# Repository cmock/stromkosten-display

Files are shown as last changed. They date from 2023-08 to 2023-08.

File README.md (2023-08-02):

# Stromkosten-Display

Zeigt auf einer 8x8-Matrix aus WS2812-LEDs die Strompreise der
nächsten Stunden und den Status des Stromnetzes an. 

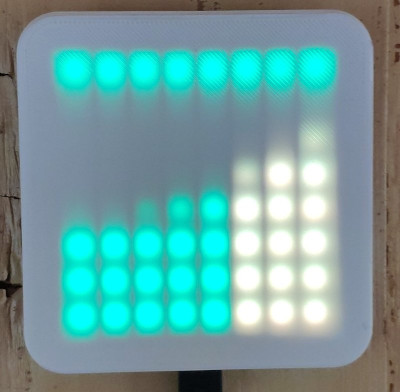
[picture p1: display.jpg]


Primär interessant für österreichische Haushalte mit dynamischen
Stromtarifen, die Idee ist, die Preise im Blick zu haben, bevor man
Großverbraucher einschaltet.

Die Preise kommen über die
[aWATTar-API](https://www.awattar.at/services/api/), der Status von
[APG](https://www.apg.at/powermonitor/#c3883). 

## Ablesen

Der linke senkrechte Balken ist der Preis der aktuellen vollen Stunde,
nach rechts sind dann die folgenden Stunden.

Die Länge und Farbe der Balken gibt den Preis an, grün bis 8¢/kWh,
gelb bis 12¢/kWh, rot darüber, und blau für negative Preise.

Der horizontale Balken ganz oben ist der Status des Stromnetzes gemäß
[APG Powermonitor](https://www.apg.at/powermonitor/), passend zu den
stundenweisen Preisbalken darunter. Grün ist OK, Rot ist Spitzenlast.

## Hardware

* Ein ESP32, das Gehäuse ist für
  [diesen](https://www.az-delivery.de/products/esp32-dev-kit-c-unverlotet?variant=32437204549728).
  Tunlichst einen ohne Pin-Header nehmen, im Gehäuse ist dafür kein Platz.
* eine 8x8-Matrix aus WS2812-RGB-LEDs, wie [diese](https://www.az-delivery.de/products/u-64-led-panel?variant=40362432466)
* Ein 3D-gedrucktes Gehäuse, siehe Directory [CAD](./CAD/)
  
### Aufbau

5V und GND der LED-Matrix verbinden, GPIO16 vom ESP (`LED_PIN` im Code) mit
dem Datenpin der Matrix, fertig.

Evtl zuerst mal [WLED](https://install.wled.me/) draufflashen, das
geht einfach und man kann die Funktion der Hardware damit schön und
bunt prüfen.

### Gehäuse

[basis.stl](CAD/basis.stl) in einer undurchsichtigen Farbe,
[abdeckung.stl](CAD/abdeckung.stl) in transparentem oder weißem
Filament drucken.

Die LED-Matrix von hinten in die Basis klemmen (oder mit Heißkleber
nachhelfen), Pixel #1 kommt nach links oben. Das ESP-board einfach
dahinterlegen, sinnvollerweise mit einer Isolationsschicht dazwischen.
Mit 3mm-Spaxen an die Wand, Abdeckung drauf, fertig.

## Installation

Software-Installation: basiert auf
[PlatformIO](https://platformio.org/).

1) `include/config.h.dist` auf `include/config.h` kopieren und
editieren (WiFi-Daten, Schwellwerte für die Display-Farben)

2) `platformio.ini` ggf anpassen in sachen Upload

3) `pio run -t upload`

## Security-Warnung

Die APIs sind über HTTPS erreichbar. TL;DR: *die
Zertifikatsverifikation ist im Code ausgeschaltet.*

Da die HTTPS-Libraries für ESP32 nur ein einziges Root-Cert
unterstützen, besteht bei korrekter Verwendung das Problem, daß man
bei Änderung einer der CAs der API-Server dies erst mitbekommt, wenn
es schon geschehen ist, dann das korrekte Cert finden und in den Code
integrieren muß (oder mit noch mehr Programmieraufwand das im
Filesystem speichern und einen Mechanismus zum Updaten ohne
Recompilieren vorsehen muß). 

Das war mir zu aufwendig und widerspricht der Idee "Display, das
einfach an der Wand hängt und funktioniert."

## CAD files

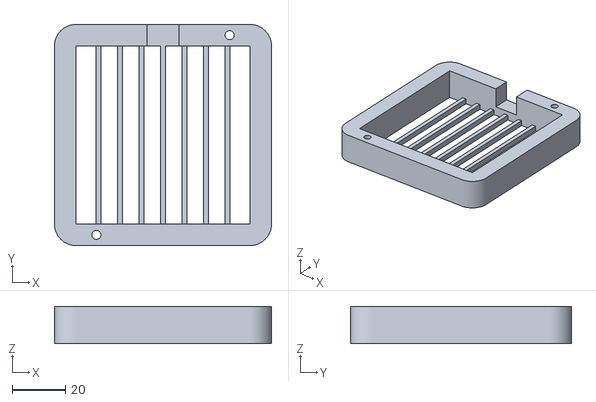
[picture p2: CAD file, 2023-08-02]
CAD/basis.stl
81.5 x 83.0 x 14.0

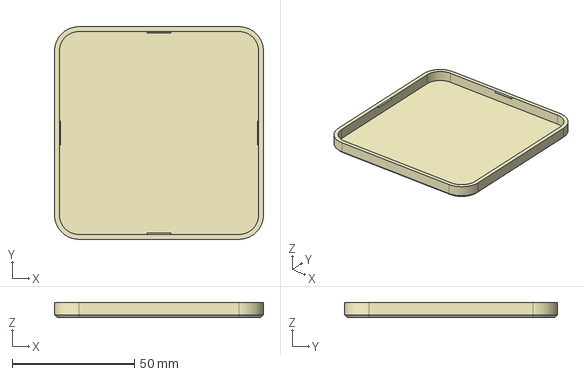
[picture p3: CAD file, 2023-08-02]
CAD/case.FCStd
85.5 x 87.0 x 6.00 mm

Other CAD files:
CAD/abdeckung.stl

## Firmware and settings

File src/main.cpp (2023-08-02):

#include <NeoPixelBusLg.h>
#include <ArduinoJson.h>
#include <FS.h>
#include <LittleFS.h>
#include <WiFi.h>
#include <WiFiMulti.h>
#include <HTTPClient.h>
#include <WiFiClientSecure.h>
#include <time.h>
#include <sntp.h>

#include "config.h"

#define LED_ROWS 8
#define LED_COLS 8
#define NUM_LEDS (LED_ROWS * LED_COLS)
#define LED_PIN 16

#define PRICE_PATH "/prices.json"
#define POWER_MONITOR_PATH "/power-monitor.json"
// how long before expiry will we try and fetch?
#define DATA_EXPIRY_BUFFER 3600
#define DATA_FETCH_RETRY 600
// how often to check if display update is necessary, in milliseconds
#define DISPLAY_INTERVAL (10*1000)

#define USER_AGENT "energy-cost-display/0.1 (ESP32HTTPClient) cm@tahina.priv.at"

#define AWATTAR_API_URL "https://api.awattar.at/v1/marketdata"

#define POWER_MONITOR_API_URL "https://awareness.cloud.apg.at/api/v1/PeakHourStatus"

#define FORMAT_LITTLEFS_IF_FAILED true


// global system state
struct {
  bool wifi_up, valid_time, valid_price_data, valid_monitor_data;
  time_t price_expiry, powermonitor_expiry,
    last_fetch_price, last_fetch_powermonitor;
} state = { false, false, false, false,
  0, 0, 0, 0,
};

NeoPixelBusLg<NeoGrbFeature, NeoEsp32I2s0Ws2812xMethod> leds(NUM_LEDS, LED_PIN);
NeoTopology<RowMajorLayout> topo(LED_ROWS, LED_COLS);

RgbColor red(255, 0, 0);
RgbColor green(0, 255, 0);
RgbColor yellow(255, 200, 0);
RgbColor blue(0,120,255);
RgbColor white(255);
RgbColor black(0);

const uint16_t left = 0;
const uint16_t right = LED_COLS - 1;
const uint16_t top = 0;
const uint16_t bottom = LED_ROWS - 1;

//const size_t json_capacity = JSON_OBJECT_SIZE(3) + 25 * JSON_OBJECT_SIZE(4);
const size_t json_capacity = 2048;
StaticJsonDocument<json_capacity> json_doc;
#define MAX_JSON_LEN 5120

#define BIG_BUF_LEN 4096
char big_buf[BIG_BUF_LEN], big_buf2[BIG_BUF_LEN];

double prices[LED_COLS];
uint16_t powermonitor[LED_COLS];

WiFiMulti wifiMulti;

bool GET(const char *url, char *buf, size_t maxlen) {
  WiFiClientSecure *client = new WiFiClientSecure;
  bool error = false;
  if(client) {
    // this client only accepts a single root cert, so either you go chasing
    // new root certs everytime the upstream server changes cert, or you
    // just skip certificate verification...
    client->setInsecure();
    HTTPClient https;
    https.setUserAgent(USER_AGENT);
    if(https.begin(*client, url)) {
      int httpCode = https.GET();
      Serial.printf("GET %s: code %d\n", url, httpCode);
      if(httpCode > 0) {
	if(httpCode == HTTP_CODE_OK || httpCode == HTTP_CODE_MOVED_PERMANENTLY) {
	  String payload = https.getString();
	  strncpy(buf, payload.c_str(), maxlen);
	}
      } else {
	Serial.println("GET failed");
	error = true;
      }
      https.end();
    } else {
      Serial.println("HTTPS.begin failed");
      error = true;
    }
    delete client;
  }
  return !error;
}

// returns timestamp of last entry, or 0 on error
time_t parse_awattar_json(char input[], time_t now) {
  time_t last_timestamp = 0;
  
  DeserializationError error = deserializeJson(json_doc, input, MAX_JSON_LEN);
  if(error) {
    Serial.print("Awattar: deserializeJson() failed: ");
    Serial.println(error.c_str());
    Serial.printf("Capacity: %d\n", json_doc.capacity());
    return 0;
  }

  const char *object = json_doc["object"];
  if(strcmp(object, "list")) {
    Serial.println("JSON: object != list");
    return 0;
  }

  now -= (now % 3600); // round to hour
  
  for (JsonObject data_item : json_doc["data"].as<JsonArray>()) {
    time_t start_timestamp = data_item["start_timestamp"].as<long long>()/1000;
    time_t end_timestamp = data_item["end_timestamp"].as<long long>()/1000;
    double marketprice = data_item["marketprice"]; 
    const char* unit = data_item["unit"];
    if(strcmp(unit, "Eur/MWh")) {
      Serial.println("JSON: unit not Eur/Mwh");
      return 0;
    }
    if(start_timestamp > last_timestamp)
      last_timestamp = start_timestamp;
    if(start_timestamp < now)
      continue;
    time_t slot = (start_timestamp - now)/3600;
    char buf[1024];
    sprintf(buf, "%d %d %.2f\n", start_timestamp, slot, marketprice);
    Serial.print(buf);
    if(slot >= LED_COLS)
      continue;
    prices[slot] = marketprice;
  }
  return last_timestamp;
}

// returns timestamp of "FirstUTC"
time_t parse_power_monitor_json(char input[], time_t now) {
  time_t first_timestamp = 0;
  
  DeserializationError error = deserializeJson(json_doc, input, MAX_JSON_LEN);
  if(error) {
    Serial.print("power_monitor: deserializeJson() failed: ");
    Serial.println(error.c_str());
    Serial.printf("Capacity: %d\n", json_doc.capacity());
    return 0;
  }

  const char *firstutc = json_doc["FirstUtc"];
  if(firstutc == NULL) {
    Serial.println("can't find FirstUtc");
    return 0;
  }
  Serial.printf("FirstUTC = <%s>\n", firstutc);
  struct tm tm;
  char *p = strptime(firstutc, "%Y-%m-%dT%H:%M:%SZ", &tm);
  if(p == NULL || *p != 0) {
    Serial.printf("strptime failed for 'FirstUtc' %s\n", firstutc);
    return 0;
  }
  first_timestamp = mktime(&tm); // should use timegm(), but that doesn't exist

  uint16_t dflt = json_doc["DefaultStatus"];
  Serial.printf("FirstUTC %d, DefaultStatus %d\n", first_timestamp, dflt);

  for(uint16_t i = 0; i < LED_COLS; i++)
    powermonitor[i] = dflt;

  now -= (now % 3600); // round to hour
  
  for (JsonObject info : json_doc["StatusInfos"].as<JsonArray>()) {
    const char *utc = info["utc"];
    uint16_t s = info["s"];
    char *p = strptime(utc, "%Y-%m-%dT%H:%M:%SZ", &tm);
    if(p == NULL || *p != 0) {
      Serial.printf("strptime failed for 'utc' %s\n", firstutc);
      return 0;
    }
    time_t utc_t = mktime(&tm);
    int16_t hrs = (utc_t - now)/3600;
    if(hrs >= 0 && hrs < LED_COLS)
      powermonitor[hrs] = s;
  }
  return first_timestamp;
}

void writeFile(fs::FS &fs, const char * path, const char * message){
    Serial.printf("Writing file: %s\r\n", path);

    File file = fs.open(path, FILE_WRITE);
    if(!file){
        Serial.println("- failed to open file for writing");
        return;
    }
    if(file.print(message)){
        Serial.println("- file written");
    } else {
        Serial.println("- write failed");
    }
    file.close();
}

void fetch_awattar() {
  time_t now = time(NULL);
  // fetch
  if(!GET(AWATTAR_API_URL, big_buf, BIG_BUF_LEN))
    return;
  // copy big_buf because json parsing modifies it...
  memcpy(big_buf2, big_buf, BIG_BUF_LEN);
  // check
  time_t last_price = parse_awattar_json(big_buf, now);
  if(last_price == 0)
    return;
  // update expiry time
  state.price_expiry = last_price - 9 * 3600;
  state.valid_price_data = true;
  // write cache
  writeFile(LittleFS, PRICE_PATH, big_buf2);
}

void fetch_power_monitor() {
  time_t now = time(NULL);
  // fetch
  if(!GET(POWER_MONITOR_API_URL, big_buf, BIG_BUF_LEN))
    return;
  // copy big_buf because json parsing modifies it...
  memcpy(big_buf2, big_buf, BIG_BUF_LEN);
  // check
  time_t start_time = parse_power_monitor_json(big_buf, now);
  if(start_time == 0)
    return;
  // update expiry time
  state.powermonitor_expiry = start_time + 25 * 3600;
  state.valid_monitor_data = true;
  // write cache
  writeFile(LittleFS, POWER_MONITOR_PATH, big_buf2);
}
  

bool readFile(fs::FS &fs, const char * path, char *buf, size_t maxlen){
  char *p = buf;
  size_t avail = maxlen;
  Serial.printf("Reading file: %s\r\n", path);

  File file = fs.open(path);
  if(!file || file.isDirectory()){
    Serial.println("- failed to open file for reading");
    return false;
  }

  Serial.println("- read from file:");
  while(file.available()){
    size_t n = file.readBytes(p, avail);
    Serial.println(n);
    p+=n;
    avail-=n;
    if(avail <= 0) {
      Serial.println("No more buffer space while reading");
      return false;
    }
  }
  file.close();
  return true;
}

// read cached data and expiry timestamps
bool read_caches() {
  time_t now = time(NULL);
  
  if(readFile(LittleFS, PRICE_PATH, big_buf, BIG_BUF_LEN)) {
    Serial.println("read " PRICE_PATH);
    time_t last_price = parse_awattar_json(big_buf, now);
    if(last_price != 0) {
      // update expiry time
      state.price_expiry = last_price - 9 * 3600;
      state.valid_price_data = true;
    }
  }
  if(readFile(LittleFS, POWER_MONITOR_PATH, big_buf, BIG_BUF_LEN)) {
    Serial.println("read " POWER_MONITOR_PATH);
    time_t first_monitor = parse_power_monitor_json(big_buf, now);
    if(first_monitor != 0) {
      state.powermonitor_expiry = first_monitor + 25 * 3600;
      state.valid_monitor_data = true;
    }
  }
  return true;
}


// col: 0..7, len: 0..8
void bar(uint16_t col, double len, RgbColor color, RgbColor bgcolor) {
  if(col >= LED_COLS)
    col = LED_COLS-1;
  if(len > 1.0)
    len = 1.0;

  uint16_t full = fabs(len) * (LED_ROWS-1); // integer part
  float frac = fabs(len) * (LED_ROWS-1) - full;
  //  Serial.printf("blend: len %.2f, full %d, frac %.1f\n", len, full, frac);
  
  // clear
  for(uint16_t y = 0; y < LED_ROWS; y++)
    leds.SetPixelColor(topo.Map(col, y), bgcolor);
  for(uint16_t y = 1; y <= full; y++)
    leds.SetPixelColor(topo.Map(col, LED_ROWS-y), color);
  if(frac > 0.09)
    leds.SetPixelColor(topo.Map(col, LED_ROWS-full-1),
		       RgbColor::LinearBlend(black, color, frac));
  // always set lowest pixel
  leds.SetPixelColor(topo.Map(col, LED_ROWS-1), color);
}

void printTime()
{
  struct tm timeinfo;
  time_t now;
  if(!getLocalTime(&timeinfo)){
    Serial.println("No time available (yet)");
    return;
  }
  Serial.println(&timeinfo, "%A, %B %d %Y %H:%M:%S");
  time(&now);
  Serial.println(now);
}

// Callback function (get's called when time adjusts via NTP)
void timeavailable(struct timeval *t)
{
  Serial.println("Got time adjustment from NTP!");
  state.valid_time = true;
}

void print_timers() {
  time_t now;
  time(&now);
  Serial.println("Timers:");
  Serial.print("Prices: ");
  Serial.print(state.price_expiry);
  Serial.print(" - ");
  Serial.println(state.last_fetch_price - now);
  Serial.print("Monitor: ");
  Serial.print(state.powermonitor_expiry);
  Serial.print(" - ");
  Serial.println(state.last_fetch_powermonitor - now);
}

void ls_littlefs() {
  File root = LittleFS.open("/");
  if(!root) {
    Serial.println("ls_littlefs: failed to open /");
    return;
  }
  if(!root.isDirectory()) {
    Serial.println("ls_littlefs: / is not a directory");
    return;
  }
  File file = root.openNextFile();
  while(file) {
    Serial.printf("%3s %6d %s\n", file.isDirectory() ? "DIR" : "",
		  file.size(), file.name());
    file = root.openNextFile();
  }
}
  

void setup() {
  Serial.begin(115200);
  while(!Serial);
  delay(2000);
  Serial.println();
  Serial.println("Starting...");
  Serial.print("json_capacity: "); Serial.println(json_capacity);
  //  FastLED.addLeds<NEOPIXEL, LED_PIN>(leds, NUM_LEDS);
  leds.Begin();
  leds.SetLuminance(LED_BRIGHTNESS);
  leds.ClearTo(black);
  leds.SetPixelColor(0, green); // show power on state
  leds.SetPixelColor(1, red); // show waiting for wifi
  leds.Show();

  sntp_set_time_sync_notification_cb( timeavailable );
  // we don't need local time offset
  configTime(0, 0, NTP_SERVER, NULL, NULL);
  
  WiFi.setHostname(HOSTNAME);
  wifiMulti.addAP(WIFI1_SSID, WIFI1_PSK);
  wifiMulti.addAP(WIFI2_SSID, WIFI2_PSK);


  if(!LittleFS.begin(FORMAT_LITTLEFS_IF_FAILED)){
    Serial.println("LittleFS Mount Failed");
    return;
  }
  
  Serial.println("LittleFS mounted, Running.");
  ls_littlefs();
}


void loop() {
  time_t now;
  static unsigned long last_display_millis = 0;

  if(wifiMulti.run() == WL_CONNECTED) {
    state.wifi_up = true;
  } else {
    state.wifi_up = false;
  }

  if(state.wifi_up && state.valid_time &&
     last_display_millis + DISPLAY_INTERVAL < millis()) {
    last_display_millis = millis();
    // check if we need to do some API calls
    read_caches();
    time(&now);
    if(state.last_fetch_price + DATA_FETCH_RETRY < now &&
       state.price_expiry < now + DATA_EXPIRY_BUFFER) {
      Serial.println("fetch awattar");
      fetch_awattar();
      state.last_fetch_price = now;
      print_timers();
    }
    if(state.last_fetch_powermonitor + DATA_FETCH_RETRY < now &&
       state.powermonitor_expiry < now + DATA_EXPIRY_BUFFER) {
      Serial.println("fetch APG");
      fetch_power_monitor();
      state.last_fetch_powermonitor = now;
      print_timers();
    }
  }
    

  if(state.valid_price_data) {
    for (uint16_t i = 0; i < LED_COLS; i++) {
      bar(i, prices[i]/PRICE_MAX, (prices[i] >= RED_LIMIT ? red : 
				   (prices[i] >= YELLOW_LIMIT ? yellow :
				    (prices[i] < 0 ? blue :
				     green))),
	  black);
    }
    //Serial.println("bars");
  }
  if(state.valid_monitor_data) {
    // show monitor data
    for (uint16_t i = 0; i < LED_COLS; i++)
      leds.SetPixelColor(topo.Map(i, 0), powermonitor[i] == 1 ? green : red);
  }
  if(!state.valid_price_data && !state.valid_monitor_data) { // show system state
    // first N pixels:
    // 0 green -- power on
    // 1 wifi
    // 2 time
    // 3 price data
    // 4 power monitor data
    leds.ClearTo(black);
    leds.SetPixelColor(0, green);
    leds.SetPixelColor(1, state.wifi_up ? green : red);
    leds.SetPixelColor(2, state.valid_time ? green : red);
    leds.SetPixelColor(3, state.valid_price_data ? green: red);
    leds.SetPixelColor(4, state.valid_monitor_data ? green: red);
    //    delay(500);
  }
  leds.Show();
}

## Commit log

2023-06-04 case CAD added
    [case.FCStd]
2023-06-07 resized case to really fit the board plus USB plug
    [case.FCStd]
2023-06-12 fix bug w/price data expiry; negative prices in blue
    [main.cpp]
2023-08-02 ready for release
    [abdeckung.stl, basis.stl, case.FCStd]
